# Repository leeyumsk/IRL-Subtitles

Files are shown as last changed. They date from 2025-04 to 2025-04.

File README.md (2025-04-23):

# IRL-Subtitles

Using techniques similar to human perception to localize sounds and speakers.

## Project Details

The final goal of the project is to make AR-Glasses that can display text taken from microphones to be displayed on a heads up display to the user. The system integrates a microphone array, and a camera to localize sound, transcribe speech, and visually present captions on a laptop screen connected to the glasses. This project would ideally be combined with a smart glass display/platform in the future.

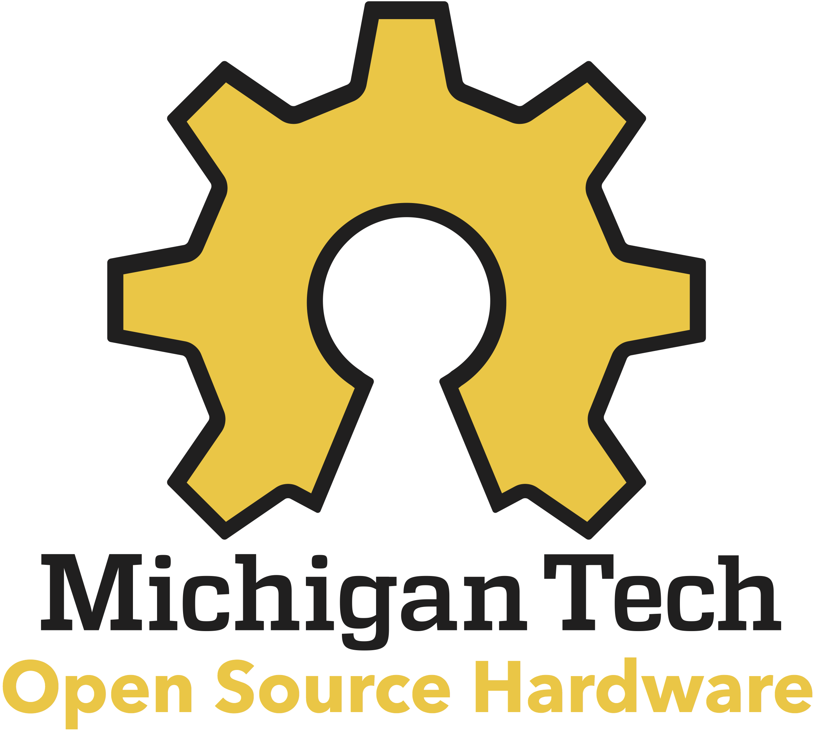
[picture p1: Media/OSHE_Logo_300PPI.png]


## Current State
The current state of the project is that there is no processing that is happening locally on the board, all the data is being streamed over to a computer to be processed and displayed. There are one ESP32-S3 wroom 1U that are being used to get audio and one ESP32-S3 eye that is acting as an AP, camera, and handling the data routing. This is a battery powered data colletion unit.

## Project Structure
The project consists of:
1. [Firmware](#1-firmware)
2. [Software](#2-software)
3. [Hardware](#3-hardware)
4. [Extra Documentation](#4-extra-documentation)

Each is structured into their own folders, and sub groups.

### 1. [Firmware](/Firmware/README.md)
This is the code that is running on the ESP32. Most of the code here is for data collection and transmission. This code has two main parts, one that will go on the arm board and one that goes on the eye. This was made, built, and flashed using vscode. 

#### Requirements
- ESP32 IDF
- Target set to ESP32-S3

### 2. [Software](/Software/README.md)
This is the code that will be run on the computer to process the data that is streamed. Due to time constraints the integration of the audio localization was not included in the OpenCV and speech to text display.

### 3. [Hardware](/Hardware/README.md)
This has both the PBC and KiCad files and the glasses cad models.
The main components are:
1. Arm boards - Holds the power management and mics that collect teh audio data.
2. ESP32S3 eye - Collects the visual data and acts as an access point to route the data.
3. [PowerBoost 1000 Charger](https://www.adafruit.com/product/2465) this handle the battery.
4. Frames - Holds all components in a glasses form to be a wearable design.

#### KiCad
This has the KiCad models that were to produce the boards. That includes the schematics, the PCB files, and gerber files to order the glasses.

#### Onshape
Onshape was used to the frames that the PCBs will fit in on the glasses.

### 4. [Extra Documentation](/Extra%20Documentation/README.md)
This is all the documentation that was created in the testing and researching on creating the glasses. This also has the pin outs that were used on the glasses for reference.

## What the Project could use
1. Faster processing, moving computation on the the board.
2. Better integration between programs, face detect, sound location, and speech to text.
3. Localization of sound implemented. 
4. Battery management within code.
5. Redesign/flip the ports for the eye adapter board be able to connect to eye.

## Helpful Links
https://github.com/espressif/esp-who/tree/master

## References

[ESP-idf examples softAP](https://github.com/espressif/esp-idf/blob/master/examples/wifi/getting_started/softAP/main/softap_example_main.c)

[ESP-idf examples station](https://github.com/espressif/esp-idf/tree/master/examples/wifi/getting_started/station)

[espressif esp-who ESP32-S3-EYE](https://github.com/espressif/esp-who/blob/master/docs/en/get-started/ESP32-S3-EYE_Getting_Started_Guide.md)

[GitHub Doc](https://docs.github.com/en/get-started/writing-on-github/getting-started-with-writing-and-formatting-on-github/basic-writing-and-formatting-syntax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)

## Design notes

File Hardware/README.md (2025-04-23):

# Hardware
All of the hardware for the project.

## PCB

The PCB has gone through many revisions before it was eventually ordered and printed. The older version are in previous versions branch.

### Version 3.2
Version 3.2 is tha iteration that is used for this guide, where there in now only one ESP32-S3 on the sides of the frames. This has two spots to place a battery on where the battery WITH LOW BATTERY SHUTOFF to the board and on to use with a socketed BMS designed like the one from adafuit, [PowerBoost 500 Charger](https://www.adafruit.com/product/1944). The adapter for the eye has also change to pass through the audio data to the other board.

Version 3.2
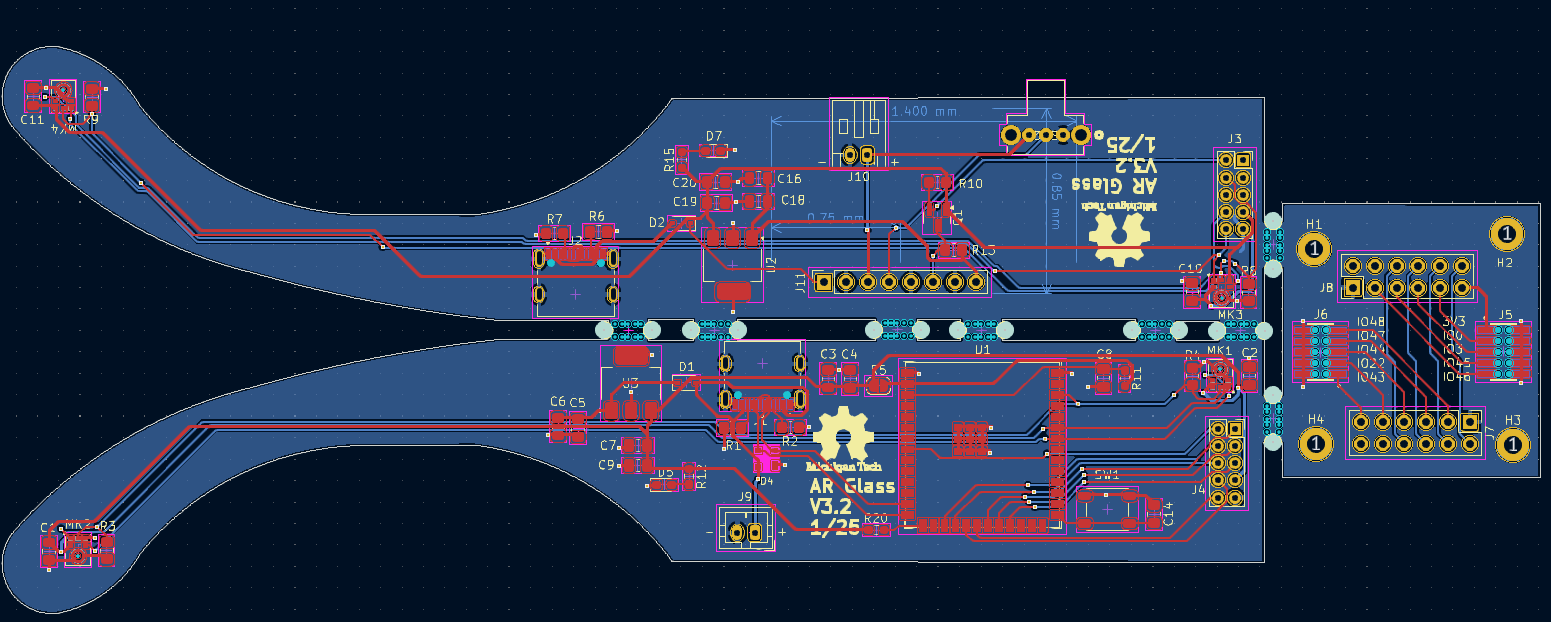
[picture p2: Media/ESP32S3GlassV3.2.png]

These are the pin out for the arm boards.
|Right| | |Left| | 
| --- | --- | - | --- | --- |
| GPIO 15 | GPIO 13 (WS) | | GND | WS | 
| GPIO 9 | GPIO 14 (SCK) | | 3V3 | SCK| 
| GPIO 10 | GPIO 21 (SD) | | x | x | 
| GPIO 11 | 3V3 | | x | SDin | 
| GPIO 12 | GND | | x | LB3v3 |

Eye Adapter Board pins:
| Top | | | | | |
| --- | ----- | ----- | ---- | ---- | ---- |
| x | x | LB3v3 | SD | SCK | WS|
| GND | IO46 | IO45 | IO3 | IO0 | 3V3 | 
| Bottom | | | | | |
| IO43 | IO21 | IO44 | IO47 | IO48 | GND |
| X | LB3v3 | SD | SCK | WS | 3V3 | 

In the hardware folder is all the production files that is needed to order the PCBs.

## Frames
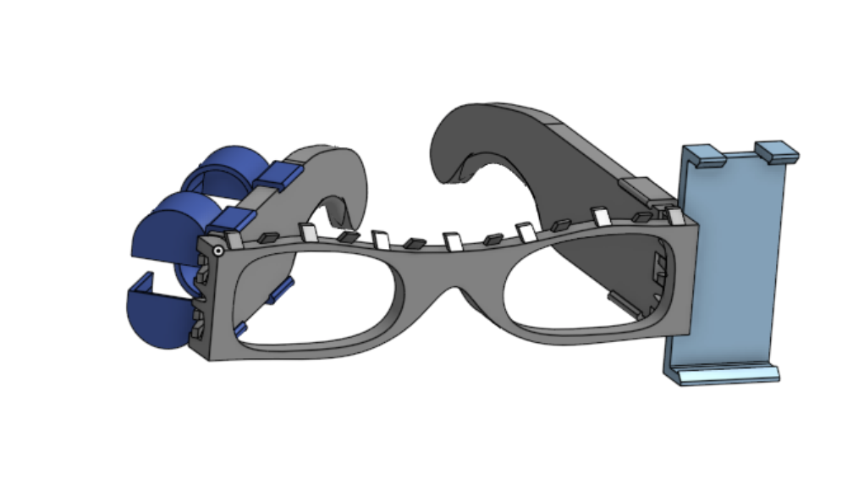
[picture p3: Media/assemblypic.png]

The frames are designed to clip together without requiring a trip to the hardware store.
The CAD model is parametrically modeled to assist with personalization.
The CAD work was done in onshape and is publicly available.
https://cad.onshape.com/documents/a7485a7ae3b222abdb51885d/w/8202e3e3be7d45f8a3fb9981/e/ac120f3095f84bb498783c7c

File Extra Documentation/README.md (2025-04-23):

# Extra Documentation

Here is where all the different files on the components, configurations, testing documents are located.

## Pin outs

(*reference to image in folder img added later once glasses are fully put together*)

Arm boards:
|Right| | |Left| | 
| --- | --- | - | --- | --- |
| GPIO 15 | GPIO 13 (WS) | | GND | WS | 
| GPIO 9 | GPIO 14 (SCK) | | 3V3 | SCK| 
| GPIO 10 | GPIO 21 (SD) | | x | x | 
| GPIO 11 | 3V3 | | x | SDin | 
| GPIO 12 | GND | | x | LB3v3 |

GPIO 41, 42, and 2 are used for the mics

There are more free pin on the ESP32S3 that are currently not being used, refer to the ESP32S3 documentation to see what pins are not tied to other functions. There is no reset button so boards will need to manually unplugged with the button held down for the first time.

Eye Adapter Board pins:
| Top | | | | | |
| --- | ----- | ----- | ---- | ---- | ---- |
| x | x | LB3v3 | SD | SCK | WS|
| GND | IO46 | IO45 | IO3 | IO0 | 3V3 | 
| Bottom | | | | | |
| IO43 | IO21 | IO44 | IO47 | IO48 | GND |
| X | LB3v3 | SD | SCK | WS | 3V3 | 

## Testing
There was a variety of tests done to figure out some of the specifications of the project.

[Audio localization](/Extra%20Documentation/Audio%20localization.md)

[Testing Audio inputs](/Extra%20Documentation/Tesing%20Audio%20inputs.md)

[Face Detection](/Extra%20Documentation/Face%20Detection.md)

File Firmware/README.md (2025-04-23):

# Firmware

Here is the firmware that will do on the boards. 
For both boards ESP-idf will need to be installed to flash both boards and configured in your chosen IDE. To follow along it is recommend to use VScode.
Install ESP-IDF into VScode from the vscode extensions: Marketplace and follow this guild to configure it on your computer [guide](https://docs.espressif.com/projects/vscode-esp-idf-extension/en/latest/installation.html) and install v5.3.2.

## Arm Boards

To flash the board follow the instructions at [VScode ESP-idf configuration](https://docs.espressif.com/projects/vscode-esp-idf-extension/en/latest/startproject.html) in this [folder, Arm boards/ESP_Arm_Boards_Station](/Firmware/Arm%20Board/ESP32_Arm_Boards_Station). This will route the data though the access point created by the ESP32S3-eye. 

Steps:
1. Configure ESP-idf
In Command Pallette / search type >ESP-IDF: Import ESP-IDF Project

2. Select target device and flashing method
Target Device: esp32s3 usb-jtag
Comp Port: com port of esp32s3 ex. com7
Flash Method: DFU

3. Import vscode configuration files
Type ">ESP-IDF: Add VS Code Configuration Folder" into the search bar
This will over write the current folder to point to where esp-idf is .

4. Build the project
Check that the bottom of the window shows the setting in step 2 (start:DFU, plug:com/port of ESP32, Chip: esp32s3 usb-jtag)

5. Flash Board
Double check the settings at the bottom of the window they should match the setting configured in step two.
Then click the lighting bolt at the bottom of the window. 

Steps 4 and 5 can be combined into 1 step by using the fire symbol that will build, flash, and monitor the board.

### Trouble shooting
There is a python script that can be run to check the output is what is expected. [playAudiofromESP32v7.py](/Firmware/Arm%20Board/ESP32_Arm_Boards_Station/playAudioFromESP32v7.py) creates a wav file that can be analysis to check that all four channels are getting audio data. The channels on the main board (right side) are channels 3 (front) and 4 (back) and on the left are channels 1 (back) and 2 (front). Will need numpy, sounddevice, and requests installed in the python environment. 
If problems arise, use the [ESP32_Arm_Board_AP](/Firmware/Arm%20Board/ESP32_Arm_Boards_AP/) to connect to and run the python script in the folder.
If trouble occurs when flashing close all terminal windows, reopen ESP-IDF terminal and flash using the following command idf.py flash

## ESP32S3-eye

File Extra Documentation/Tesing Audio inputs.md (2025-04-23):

# Audio Methods

This was one of the major things to consider this semester was how to collect the audio. There were two main ways that could be used, analog and digital.

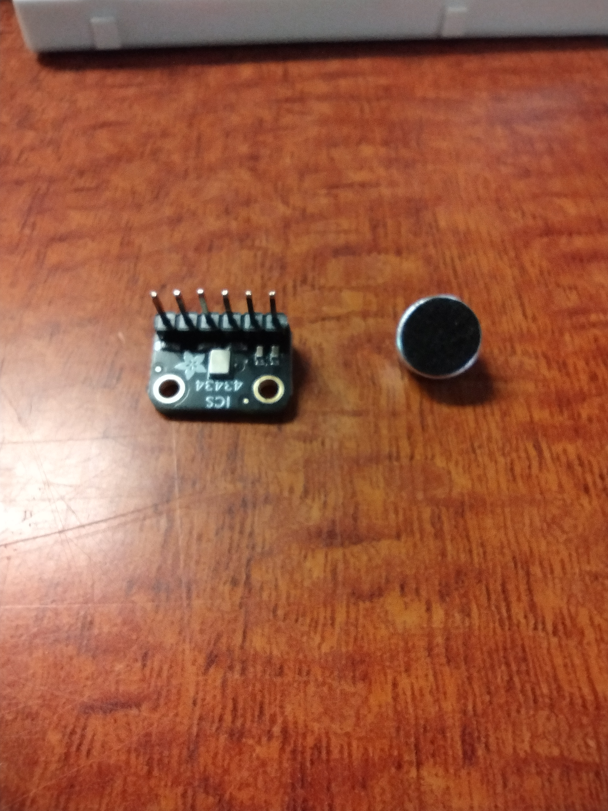
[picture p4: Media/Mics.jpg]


## Analog

To capture analog audio to be sent to the processor, the CMA-4544PF-W electret condenser microphone was used in testing. Analyzing the circuit with the oscilloscope was shown that there was a lot of noise. That there was noise that was getting through the simple filter that was made on the breadboard. This could work but would take up valuable real estate that would be limited on the board. This was coupled with the amount of time that would need to be spent to create a filter to reduce all the noise to manageable levels to process.

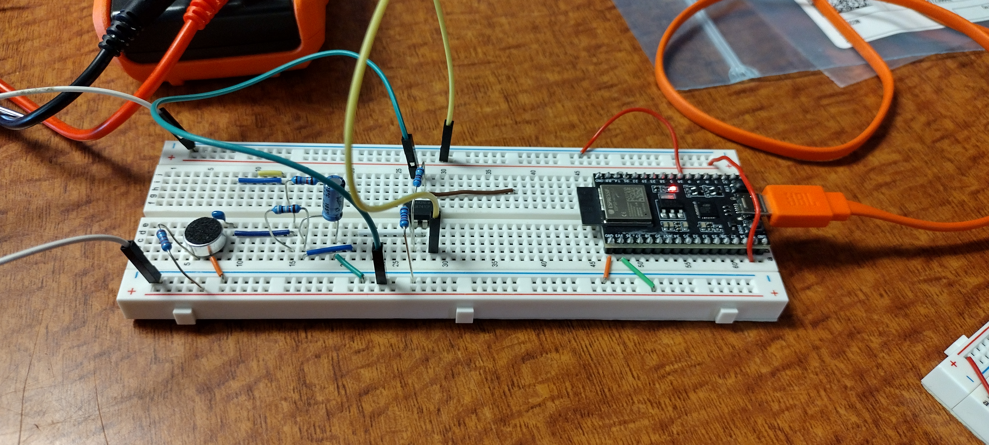
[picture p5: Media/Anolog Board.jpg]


## Digital

To capture digital audio the ICS43434 from adafruit. This works great as it was all compact and easy to breadboard and test. The only problem was to create a test that we could perform without decoding the I2S data stream, a code was needed to capture the audio. This was one of the problems as once audio was able to be captured the processing of the data was not performed correctly, as it was written for the normal esp32 dev kit, not the esp32 s3 devkit.

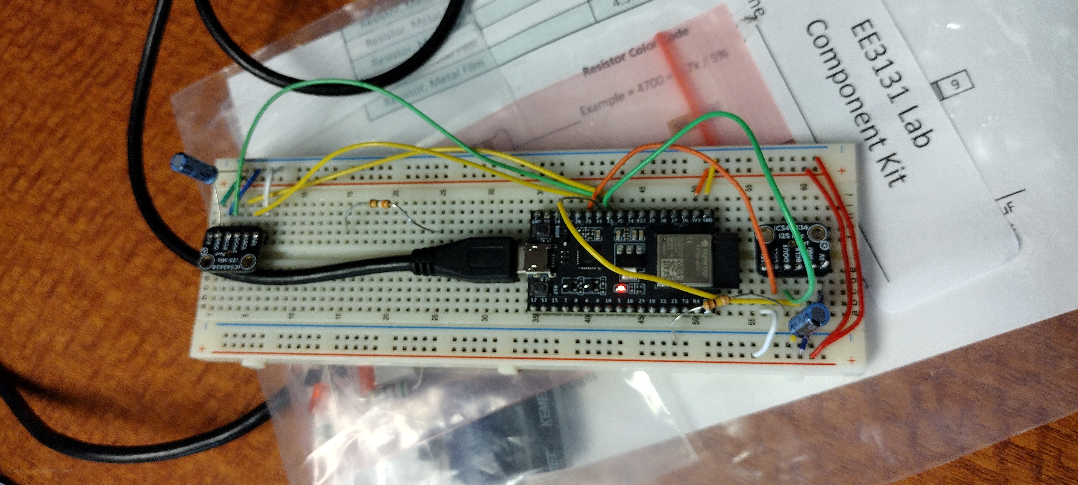
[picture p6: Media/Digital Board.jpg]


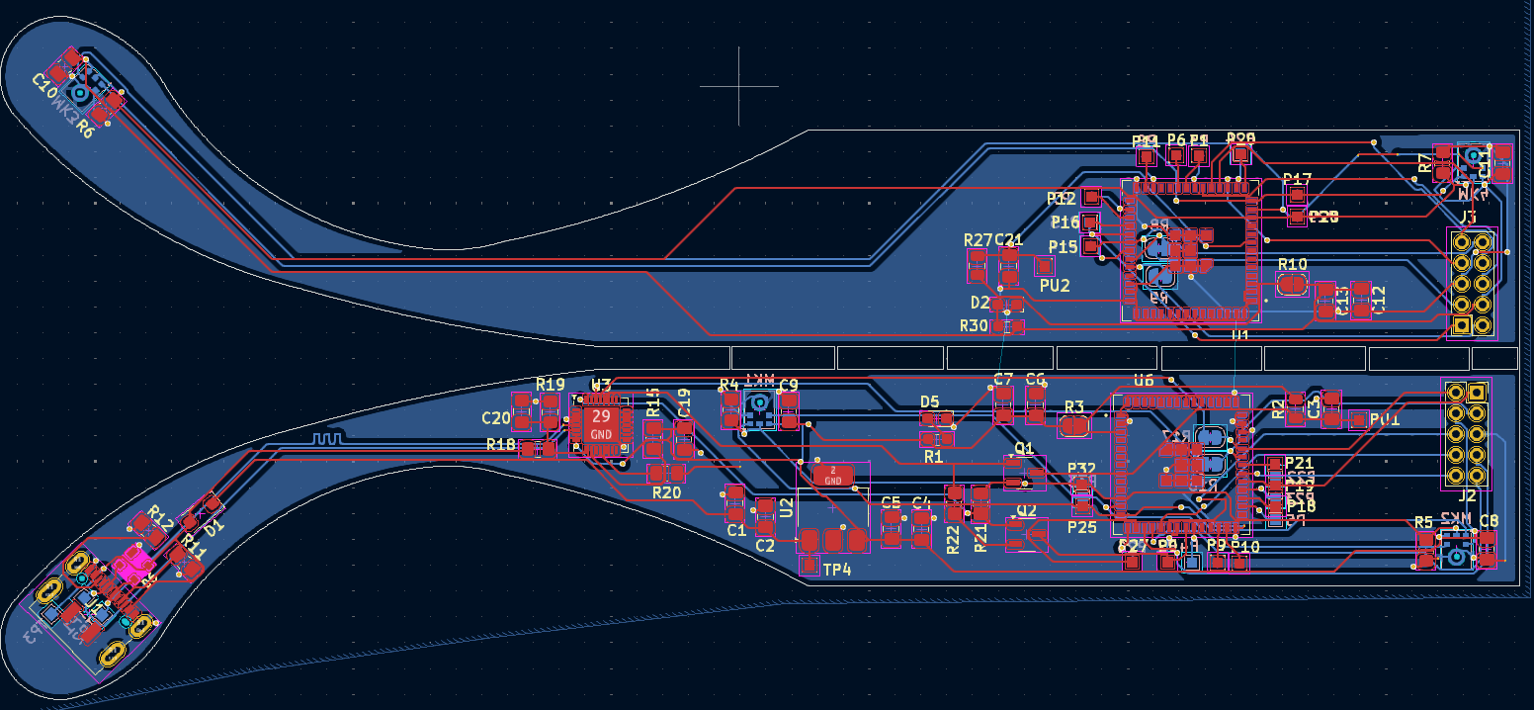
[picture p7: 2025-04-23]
Media/ESP32GlassV1.3.png

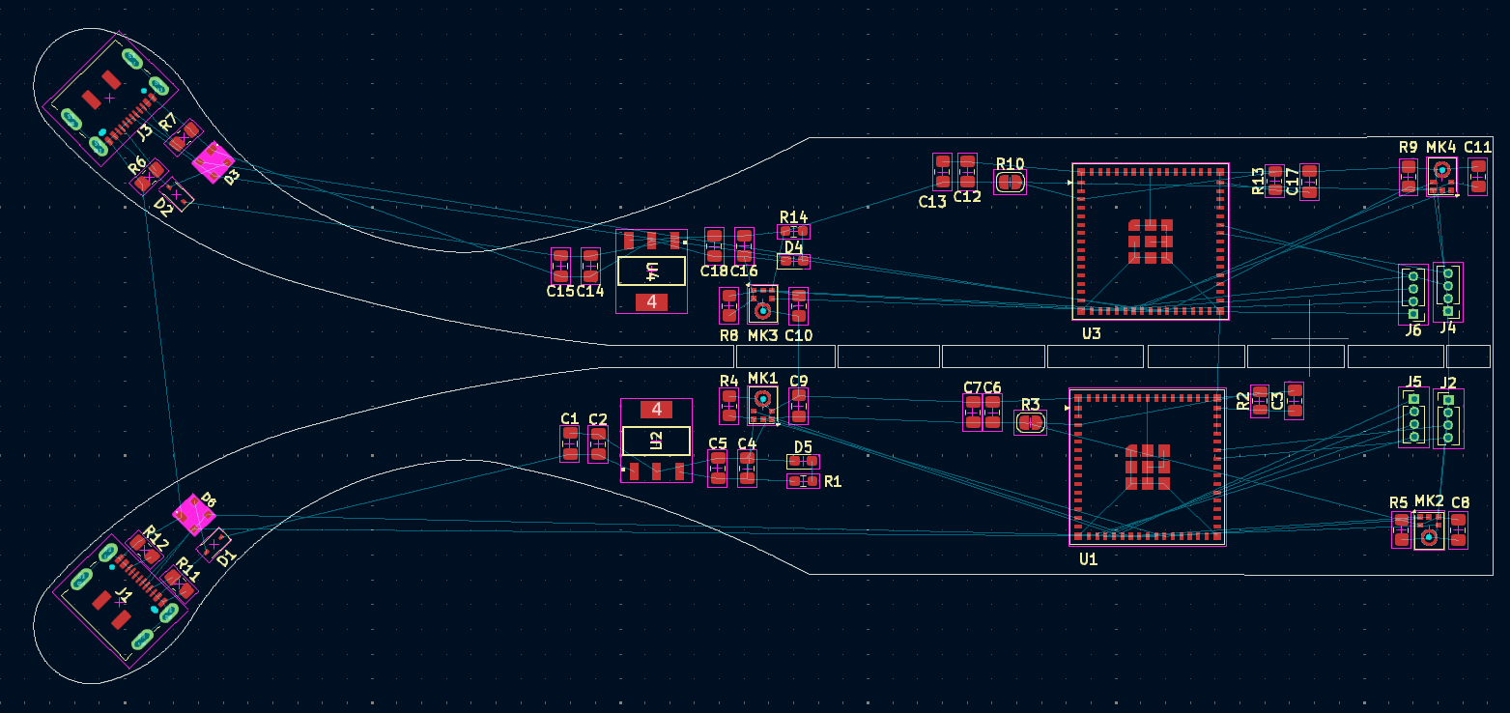
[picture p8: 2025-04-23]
Media/ESP32S3GlassV2.0.png

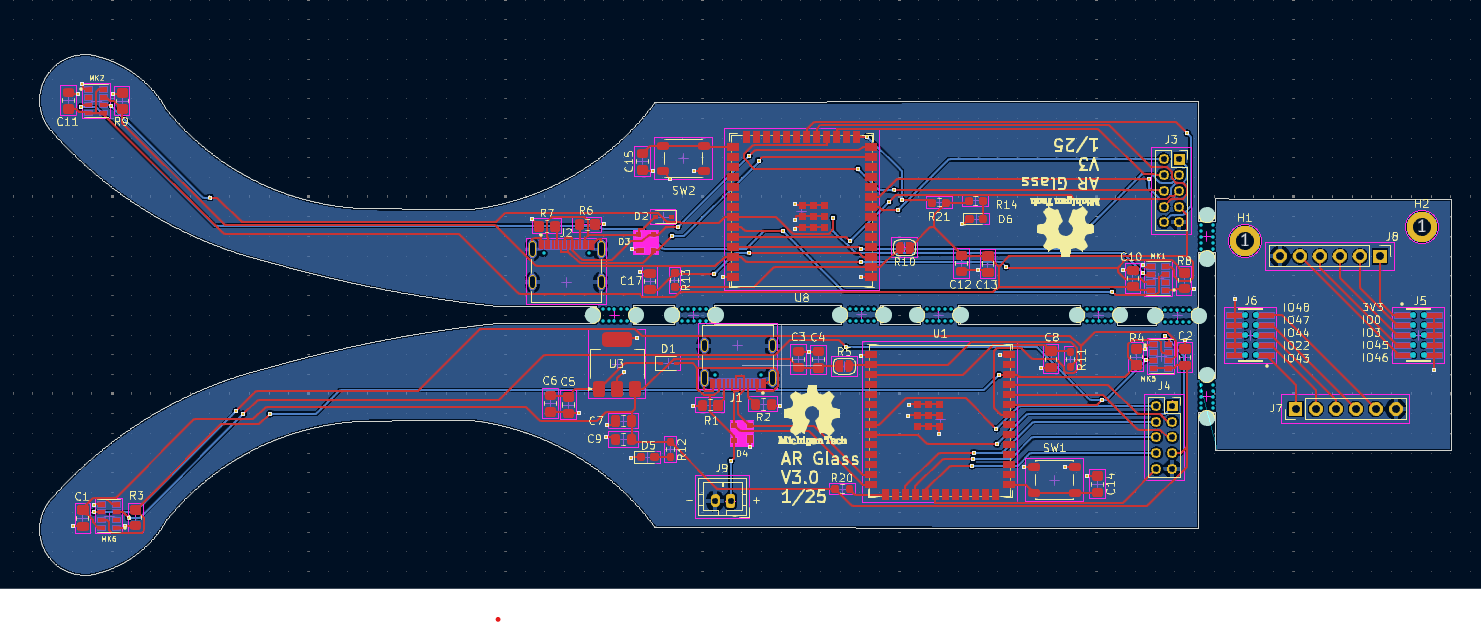
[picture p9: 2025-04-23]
Media/ESP32S3GlassV3.0.png

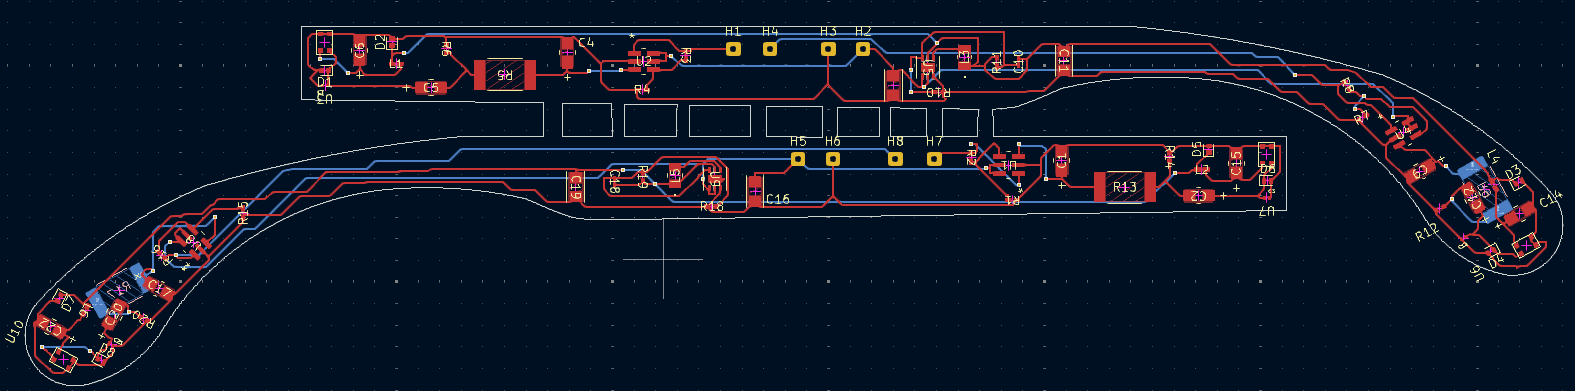
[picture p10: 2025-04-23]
Media/memsBoardV1.png

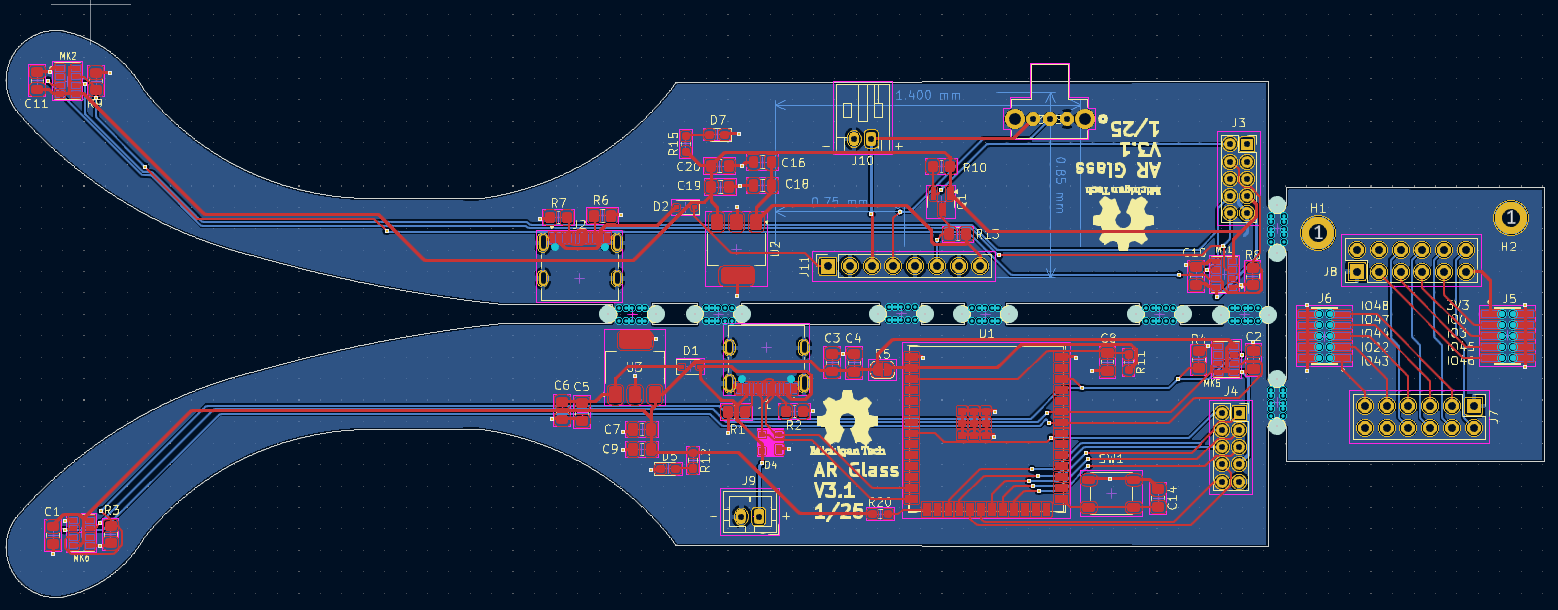
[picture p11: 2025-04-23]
Media/ESP32S3GlassV3.1.png

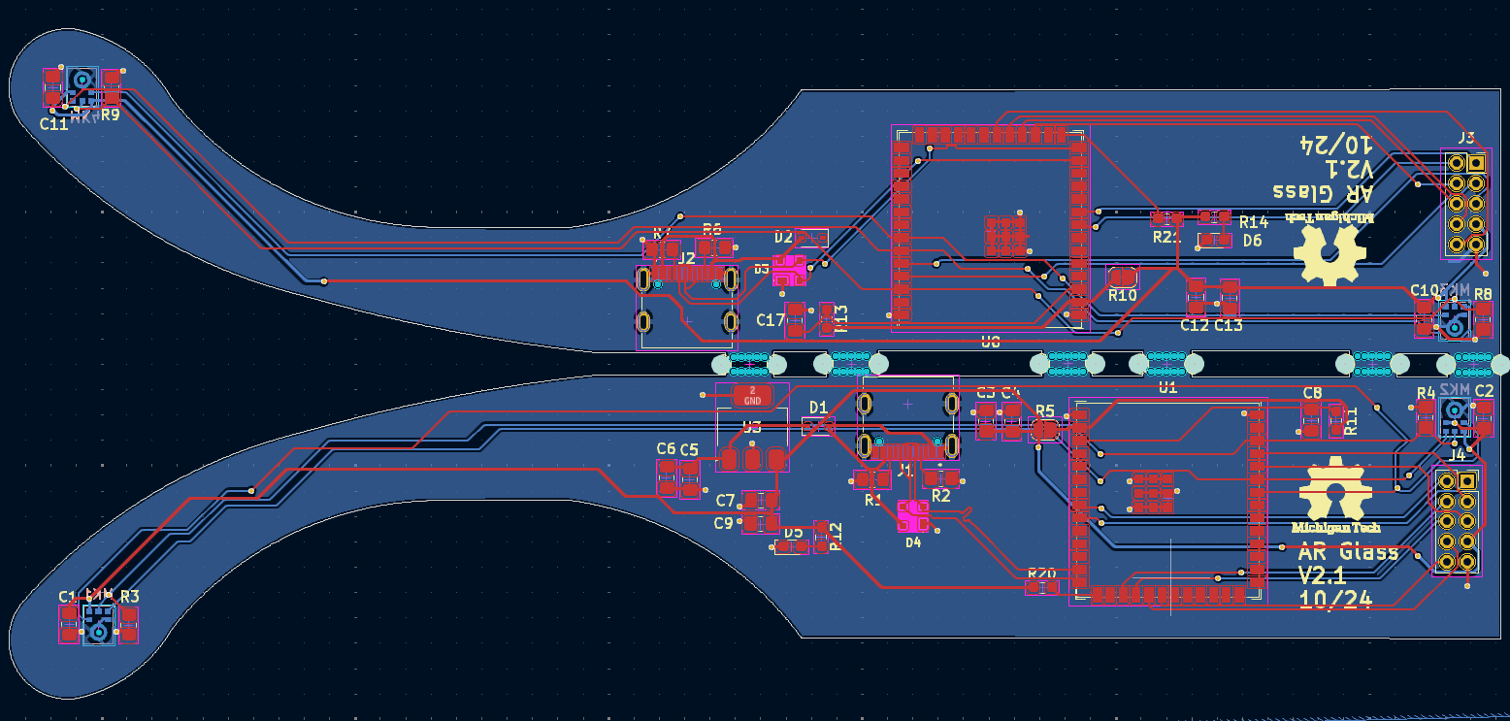
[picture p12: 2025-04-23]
Media/ESP32S3GlassV2.1.png

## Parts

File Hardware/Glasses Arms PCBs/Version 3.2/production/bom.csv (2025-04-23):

Designator | Footprint | Quantity | Value | LCSC Part #
C1, C10, C11, C14, C18, C19, C2, C4, C6, C7 | 0805 | 10 | 0.1uF | C49678
C16, C20, C3, C5, C9 | 0805 | 5 | 10uF | C15850
C8 | 0805 | 1 | 1uF | C89378
D1, D2 | D_SOD-323 | 2 | 1N5819WS | C191023
D4 | SOT143B | 1 | PRTR5V0U2X_215 | C2827688
D5, D7 | 0603 | 2 | LED | C2286
J1, J2 | HRO_TYPE-C-31-M-12 | 2 | USB_C_Receptacle_USB2.0_16P | C165948
J10 | JST_PH_S2B-PH-K_1x02_P2.00mm_Horizontal | 1 | Conn_01x02 | C173752
J11 | PinSocket_1x08_P2.54mm_Vertical | 1 | Conn_01x08_Socket | C27438
J3, J4 | PinSocket_2x05_P2.00mm_Vertical | 2 | PinSocket_2x05_P2.00mm_Vertical | C225304
J5, J6 | GCT_BD050-10-A-1-0500-L-D | 2 | BD050-10-A-0-0500-L-D
J7, J8 | PinHeader_2x06_P2.54mm_Vertical | 2 | PinHeader_2x06_P2.54mm_Vertical
J9 | JST_PH_B2B-PH-K_1x02_P2.00mm_Vertical | 1 | Conn_02x01 | C131337
MK1, MK2, MK3, MK4 | InvenSense_ICS-43434-6_3.5x2.65mm | 4 | ICS-43434 | C5656610
Q1 | SOT-23 | 1 | BSS138 | C78284
R1, R2, R6, R7 | 0805 | 4 | 5.1K | C27834
R10, R13 | 0805 | 2 | 10k | C17414
R11 | 0603 | 1 | 10K | C25804
R12, R15, R20 | 0603 | 3 | 1K | C21190
R3, R4, R8, R9 | 0805 | 4 | 100k | C149504
SW1 | SW_SPST_PTS647_Sx38 | 1 | SW_Push | C92581
SW2 | OS102011MA1QN1_CNK | 1 | OS102011MA1QN1 | C226259
U1 | ESP32-S3-WROOM-1U | 1 | ESP32-S3-WROOM-1U-N8R8 | C2980300
U2 | SOT-223-3_TabPin2 | 1 | LT1963AxST-3.3 | C459918
U3 | SOT-223-3_TabPin2 | 1 | LT1963AEST-3.3 | C459918

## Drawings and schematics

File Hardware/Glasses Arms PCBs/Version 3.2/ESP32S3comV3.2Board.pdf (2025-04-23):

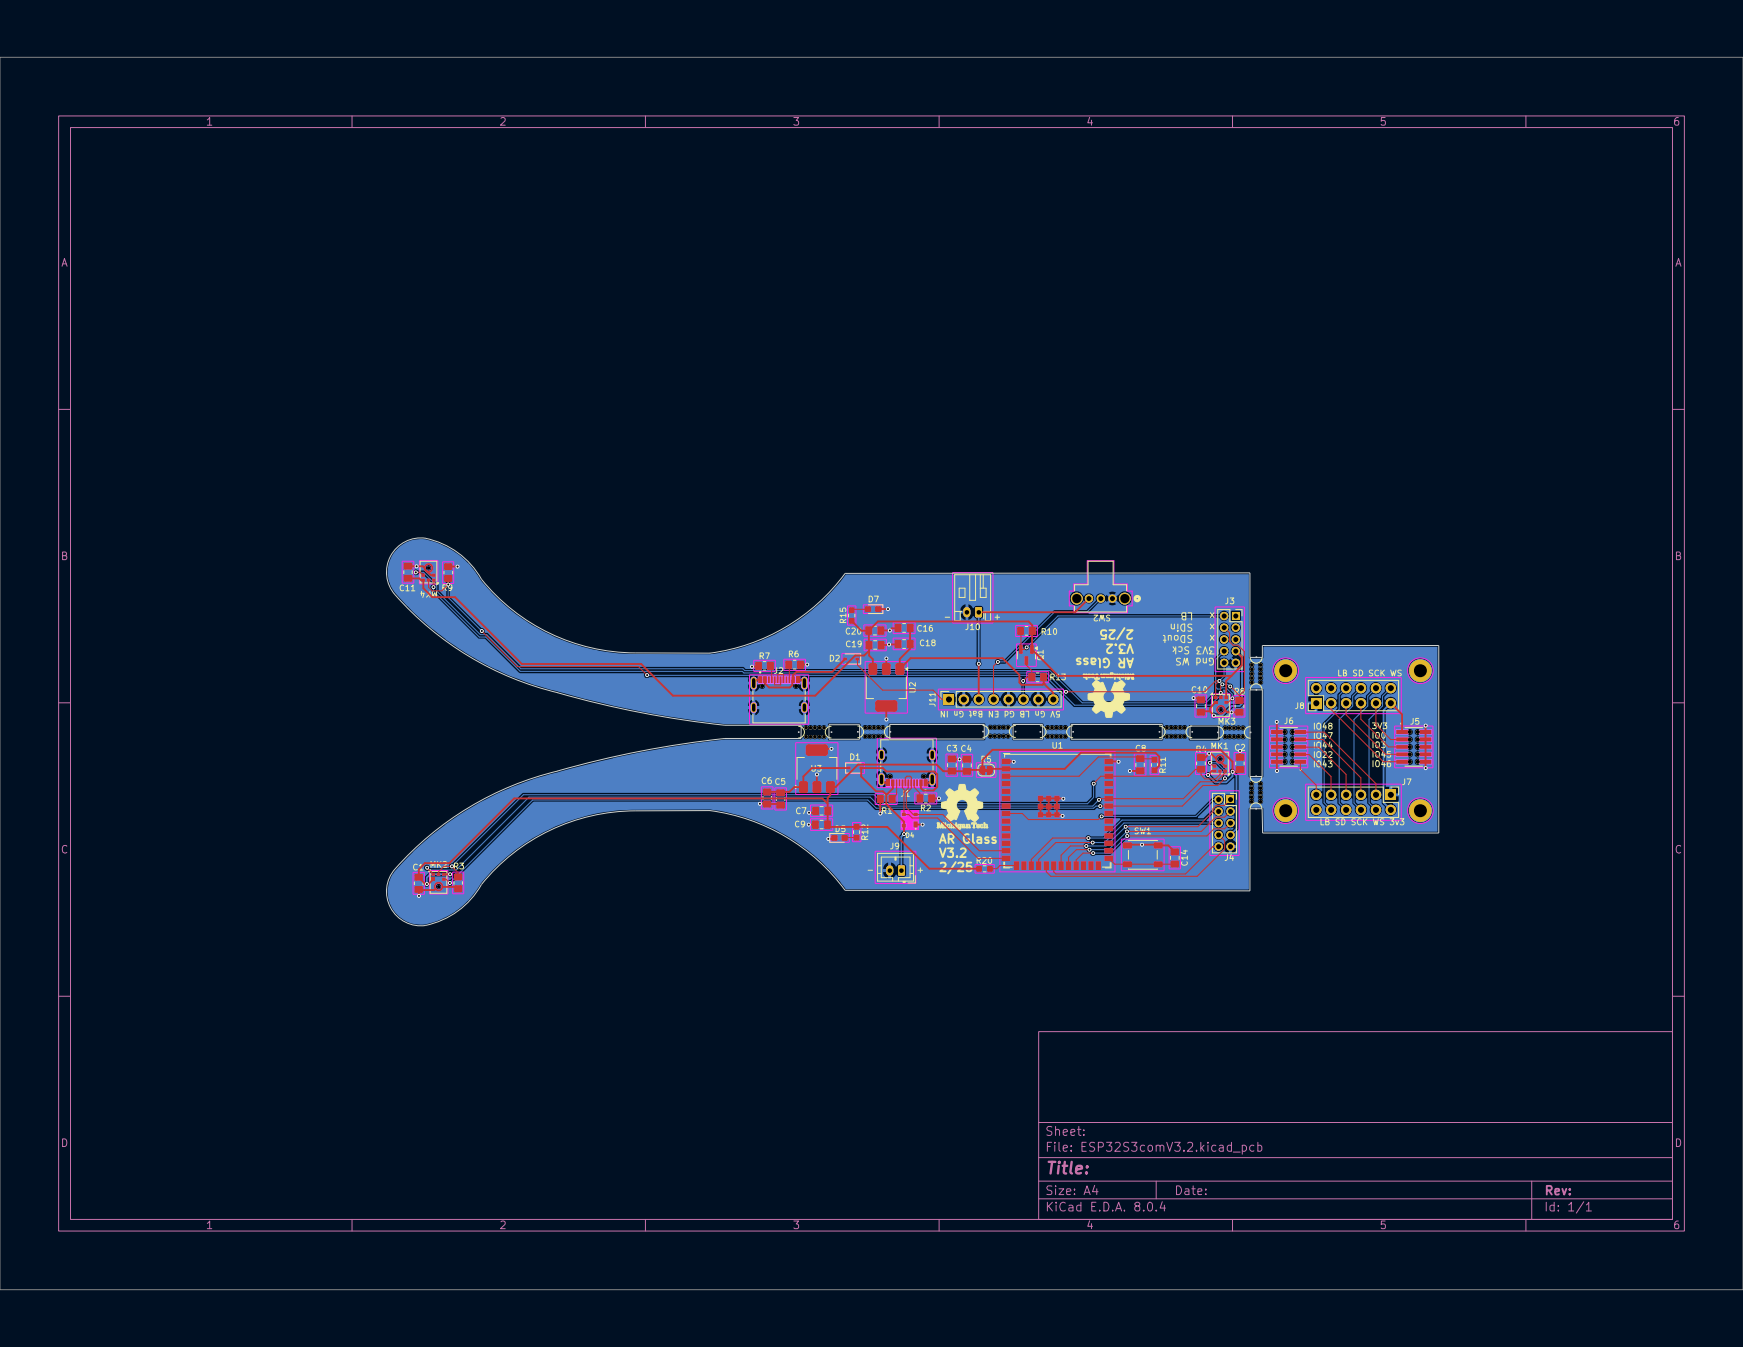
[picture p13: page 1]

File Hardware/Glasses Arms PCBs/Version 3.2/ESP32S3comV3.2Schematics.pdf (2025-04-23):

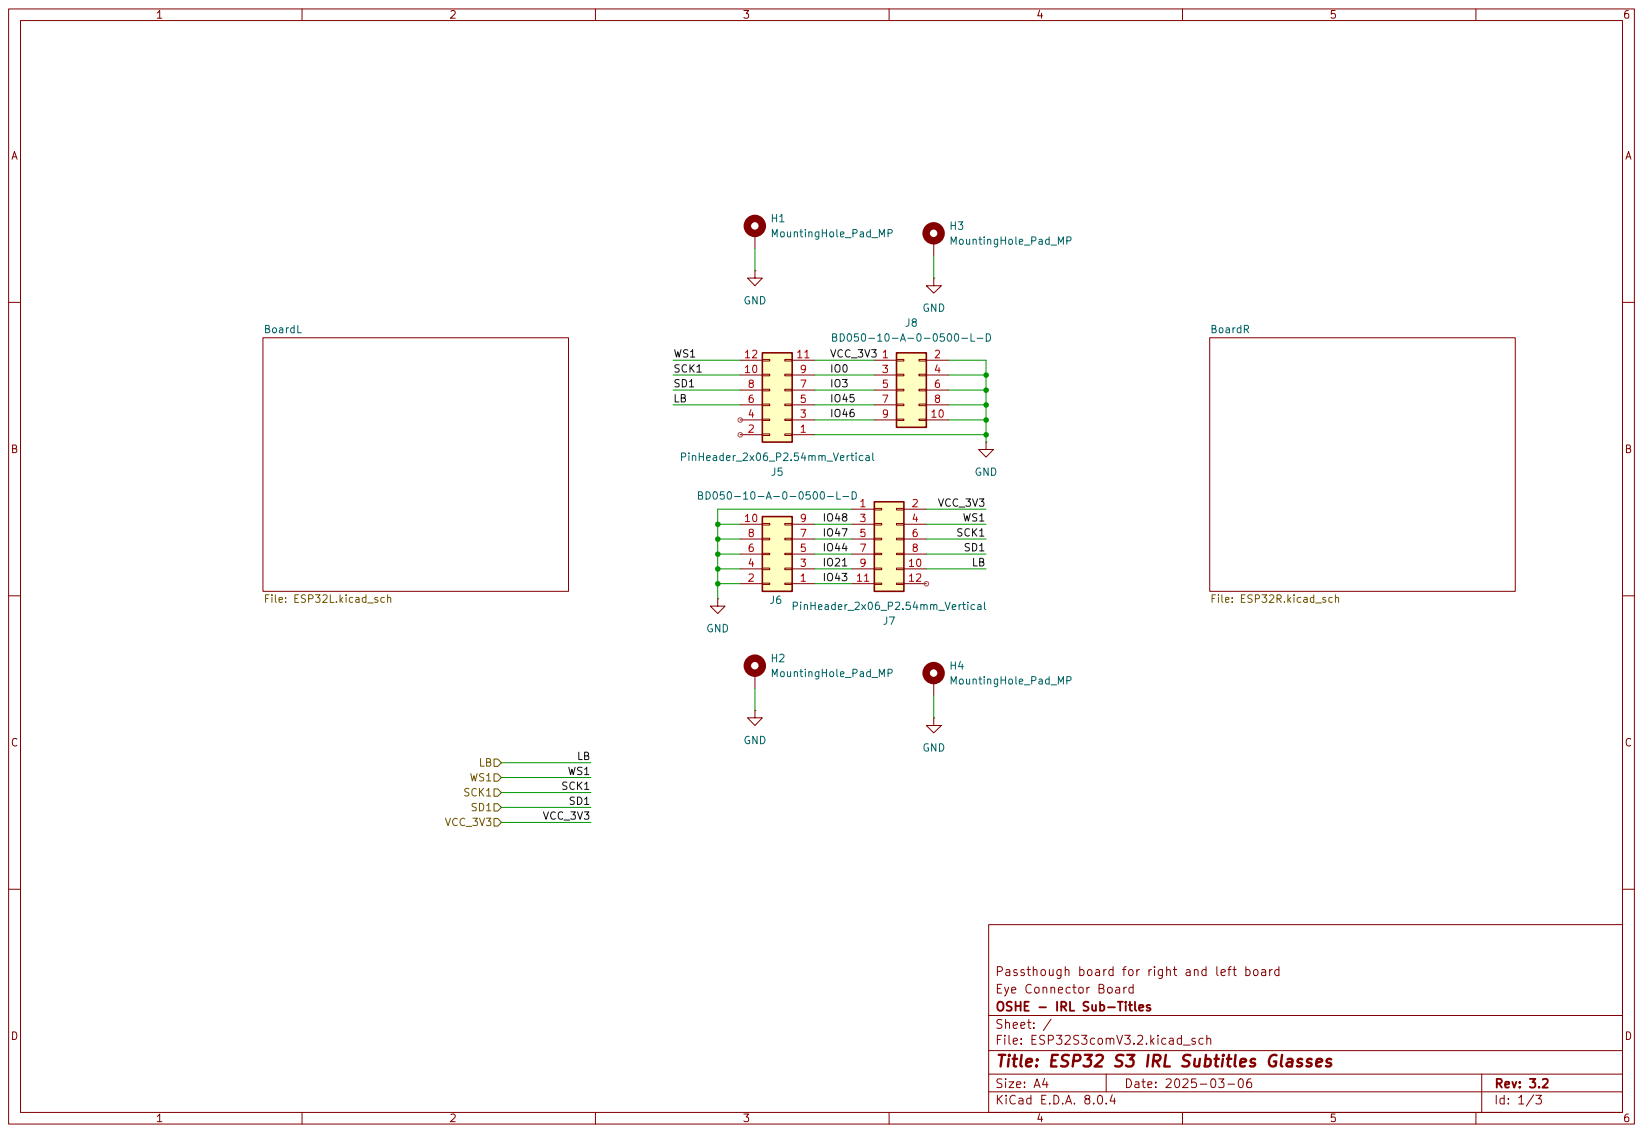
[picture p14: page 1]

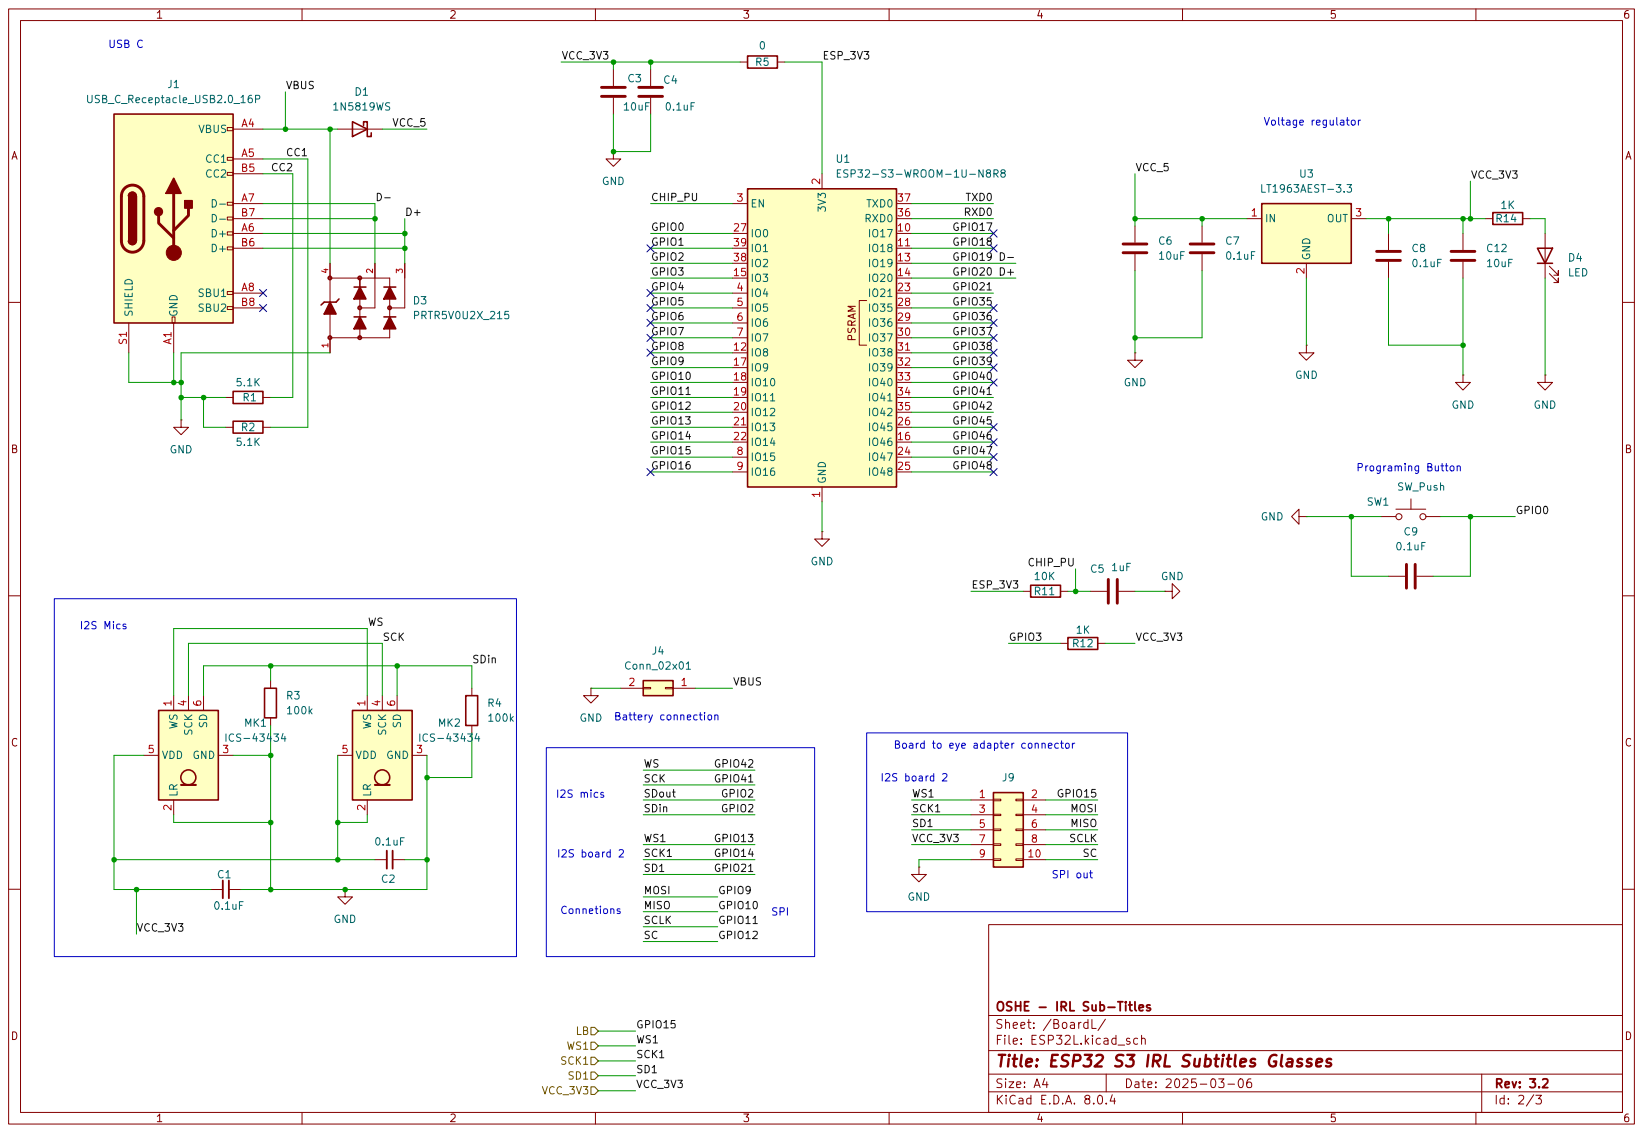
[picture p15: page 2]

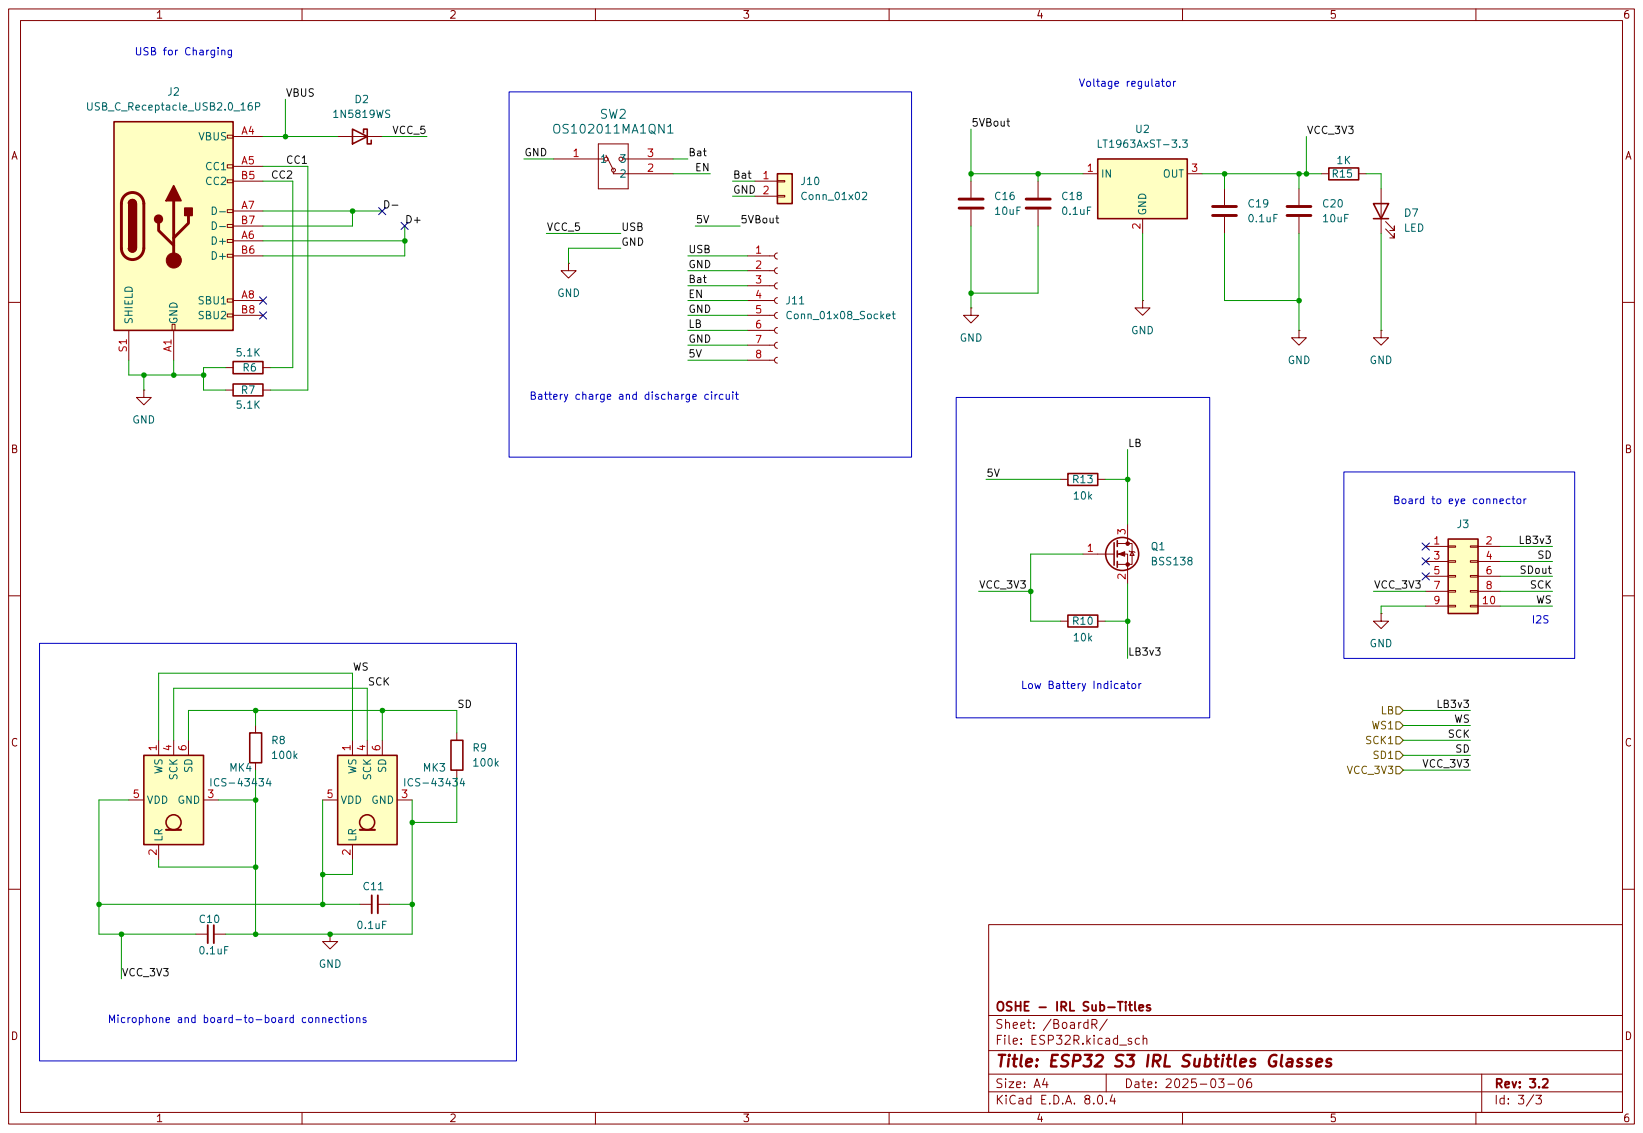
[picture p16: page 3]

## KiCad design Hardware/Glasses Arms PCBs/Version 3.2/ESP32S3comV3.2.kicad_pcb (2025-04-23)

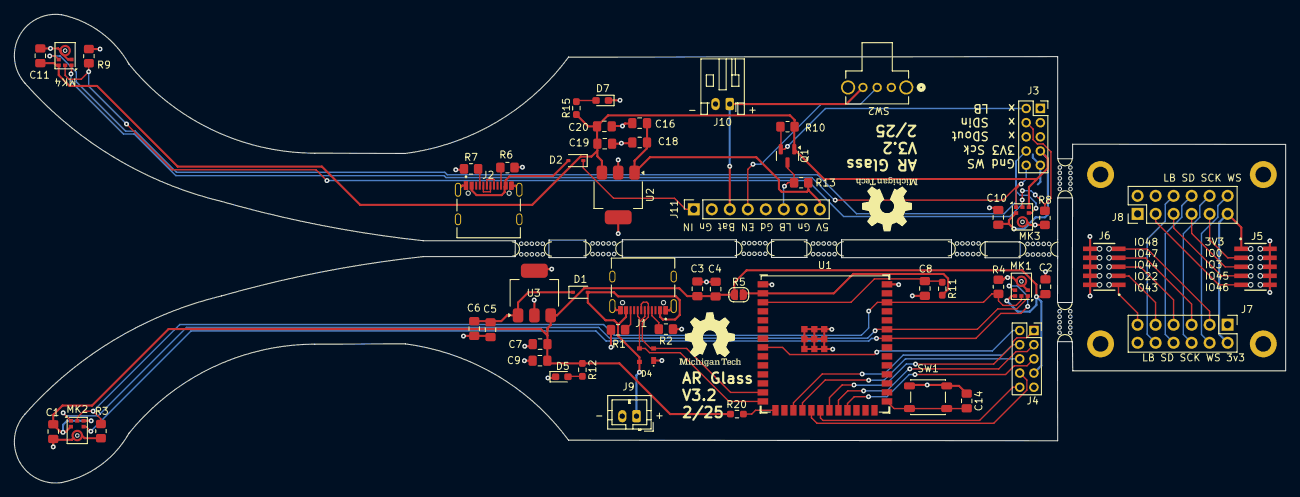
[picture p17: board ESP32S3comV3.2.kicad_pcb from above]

Board: 2 copper layers, 179.3 x 66.1 mm, 69 parts (0 on the bottom side), 54 nets.

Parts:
C1, C2, C4, C6, C7, C10, C11, C14, C18, C19: 0.1uF; C_0805_2012Metric_Pad1.18x1.45mm_HandSolder
C3, C5, C9, C16, C20: 10uF; C_0805_2012Metric_Pad1.18x1.45mm_HandSolder
C8: 1uF; C_0805_2012Metric_Pad1.18x1.45mm_HandSolder
D1, D2: 1N5819WS; D_SOD-323
D4: PRTR5V0U2X_215; SOT143B
D5, D7: LED; LED_0603_1608Metric_Pad1.05x0.95mm_HandSolder
H1, H2, H3, H4: MountingHole_Pad_MP; MountingHole_2.2mm_M2_DIN965_Pad
J1, J2: USB_C_Receptacle_USB2.0_16P; HRO_TYPE-C-31-M-12
J3, J4: PinSocket_2x05_P2.00mm_Vertical
J5, J6: BD050-10-A-0-0500-L-D; GCT_BD050-10-A-1-0500-L-D
J7, J8: PinHeader_2x06_P2.54mm_Vertical
J9: Conn_02x01; JST_PH_B2B-PH-K_1x02_P2.00mm_Vertical
J10: Conn_01x02; JST_PH_S2B-PH-K_1x02_P2.00mm_Horizontal
J11: Conn_01x08_Socket; PinSocket_1x08_P2.54mm_Vertical
MK1, MK2, MK3, MK4: ICS-43434; InvenSense_ICS-43434-6_3.5x2.65mm
Q1: BSS138; SOT-23
R1, R2, R6, R7: 5.1K; R_0805_2012Metric_Pad1.20x1.40mm_HandSolder
R3, R4, R8, R9: 100k; R_0805_2012Metric_Pad1.20x1.40mm_HandSolder
R5: 0; SolderJumper-2_P1.3mm_Open_RoundedPad1.0x1.5mm
R10, R13: 10k; R_0805_2012Metric_Pad1.20x1.40mm_HandSolder
R11: 10K; R_0603_1608Metric_Pad0.98x0.95mm_HandSolder
R12, R15, R20: 1K; R_0603_1608Metric_Pad0.98x0.95mm_HandSolder
SW1: SW_Push; SW_SPST_PTS647_Sx38
SW2: OS102011MA1QN1; OS102011MA1QN1_CNK
U1: ESP32-S3-WROOM-1U-N8R8; ESP32-S3-WROOM-1U
U2: LT1963AxST-3.3; SOT-223-3_TabPin2
U3: LT1963AEST-3.3; SOT-223-3_TabPin2
mouse-bite-3mm-slot, mouse-bite-3mm-slot-2, mouse-bite-3mm-slot-3, mouse-bite-3mm-slot-4, mouse-bite-3mm-slot-5, mouse-bite-3mm-slot-6, mouse-bite-3mm-slot-7, mouse-bite-3mm-slot-8: 0; mouse-bite-3mm-slot

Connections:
/BoardR/5V: C16.1, C18.1, J11.8, R13.1, U2.1 (IN)
/BoardR/Bat: J10.1, J11.3, SW2.3
/BoardR/CC1: J2.A5 (CC1), R7.2
/BoardR/CC2: J2.B5 (CC2), R6.2
/BoardR/D+: J2.A6 (D+), J2.B6 (D+)
/BoardR/D-: J2.A7 (D-), J2.B7 (D-)
/BoardR/EN: J11.4, SW2.2
/BoardR/LB: J11.6, Q1.3 (D), R13.2
/BoardR/LB3v3: J3.2, Q1.2 (S), R10.2
/BoardR/SCK: J3.8, MK3.4 (SCK), MK4.4 (SCK)
/BoardR/SDin: J3.4, MK3.6 (SD), MK4.6 (SD), R8.1, R9.1
/BoardR/USB: D2.1 (K), J11.1
/BoardR/VBUS: D2.2 (A), J2.A4 (VBUS), J2.A9 (VBUS), J2.B4 (VBUS), J2.B9 (VBUS)
/BoardR/VCC_3V3: C10.1, C11.1, C19.1, C20.1, J3.7, MK3.2 (LR), MK3.5 (VDD), MK4.5 (VDD), Q1.1 (G), R10.1, R15.1, U2.3 (OUT)
/BoardR/WS: J3.10, MK3.1 (WS), MK4.1 (WS)
/CC1: J1.A5 (CC1), R2.2
/CC2: J1.B5 (CC2), R1.2
/CHIP_PU: C8.1, R11.1, U1.3 (EN)
/D+: D4.3, J1.A6 (D+), J1.B6 (D+), U1.14 (IO20)
/D-: D4.2, J1.A7 (D-), J1.B7 (D-), U1.13 (IO19)
/ESP_3V3: R5.2, R11.2, U1.2 (3V3)
/Eye connect/IO0: J5.3, J8.9
/Eye connect/IO3: J5.5, J8.7
/Eye connect/IO21: J6.3, J7.9
/Eye connect/IO43: J6.1, J7.11
/Eye connect/IO44: J6.5, J7.7
/Eye connect/IO45: J5.7, J8.5
/Eye connect/IO46: J5.9, J8.3
/Eye connect/IO47: J6.7, J7.5
/Eye connect/IO48: J6.9, J7.3
/Eye connect/LB: J7.10, J8.6
/Eye connect/SCK1: J7.6, J8.10
/Eye connect/SD1: J7.8, J8.8
/Eye connect/VCC_3V3: J5.1, J7.2, J8.11
/Eye connect/WS1: J7.4, J8.12
/GPIO0: C14.2, SW1.2, U1.27 (IO0)
/GPIO2: MK1.6 (SD), MK2.6 (SD), R3.1, R4.1, U1.38 (IO2)
/GPIO3: R20.1, U1.15 (IO3)
/GPIO9: J4.4, U1.17 (IO9)
/GPIO10: J4.6, U1.18 (IO10)
/GPIO11: J4.8, U1.19 (IO11)
/GPIO12: J4.10, U1.20 (IO12)
/GPIO13: J4.1, U1.21 (IO13)
/GPIO14: J4.3, U1.22 (IO14)
/GPIO15: J4.2, U1.8 (IO15)
/GPIO21: J4.5, U1.23 (IO21)
/GPIO41: MK1.4 (SCK), MK2.4 (SCK), U1.34 (IO41)
/GPIO42: MK1.1 (WS), MK2.1 (WS), U1.35 (IO42)
/VBUS: D1.2 (A), D4.4, J1.A4 (VBUS), J1.A9 (VBUS), J1.B4 (VBUS), J1.B9 (VBUS), J9.1
/VCC_3V3: C1.1, C2.1, C3.1, C4.1, C7.1, C9.1, J4.7, MK1.5 (VDD), MK2.2 (LR), MK2.5 (VDD), R5.1, R12.1, R20.2, U3.3 (OUT)
/VCC_5: C5.1, C6.1, D1.1 (K), U3.1 (IN)
GND: C1.2, C2.2, C3.2, C4.2, C5.2, C6.2, C7.2, C8.2, C9.2, C10.2, C11.2, C14.1, C16.2, C18.2, C19.2, C20.2, D4.1, D5.1 (K), D7.1 (K), J1.A1 (GND), J1.A12 (GND), J1.B1 (GND), J1.B12 (GND), J1.S1 (SHIELD), J2.A1 (GND), J2.A12 (GND), J2.B1 (GND), J2.B12 (GND), J2.S1 (SHIELD), J3.9, J4.9, J5.2, J5.4, J5.6, J5.8, J5.10, J6.2, J6.4, J6.6, J6.8, J6.10, J7.1, J8.1, J9.2, J10.2, J11.2, J11.5, J11.7, MK1.2 (LR), MK1.3 (GND), MK2.3 (GND), MK3.3 (GND), MK4.2 (LR), MK4.3 (GND), R1.1, R2.1, R3.2, R4.2, R6.1, R7.1, R8.2, R9.2, SW1.1, SW2.1, U1.1 (GND), U1.40 (GND), U1.41 (GND), U2.2 (GND), U3.2 (GND)
unnamed: D5.2 (A), R12.2
unnamed: D7.2 (A), R15.2

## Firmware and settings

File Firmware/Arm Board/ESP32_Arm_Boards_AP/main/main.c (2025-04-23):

#include "esp_http_server.h"
#include "esp_log.h"
#include "esp_wifi.h"
#include "nvs_flash.h"
#include "esp_event.h"
#include "esp_netif.h"
#include "freertos/FreeRTOS.h"
#include "freertos/task.h"
#include "freertos/semphr.h"
#include "lwip/err.h"
#include "lwip/sys.h"
#include "esp_mac.h"
#include "driver/i2s_std.h"
#include "driver/gpio.h"
#include "esp_task_wdt.h"
#include "esp_timer.h"
#include "soc/i2s_struct.h"
#include "string.h"

// WiFi configuration
// #define EXAMPLE_ESP_WIFI_SSID      "test_ssid"
// #define EXAMPLE_ESP_WIFI_PASS      "test_pass"
#define EXAMPLE_ESP_WIFI_SSID      "myssid"
#define EXAMPLE_ESP_WIFI_PASS      "mypassword"
#define EXAMPLE_MAX_STA_CONN       4

// I2S configuration
#define I2S_SAMPLE_RATE           24000
#define I2S_BITS_PER_SAMPLE       I2S_BITS_PER_SAMPLE_32BIT
#define I2S_DMA_BUF_COUNT         8
#define I2S_DMA_BUF_LEN           128
#define BUFFER_SIZE               8192 * 2

static const char *TAG = "WiFi_AP_Audio_Stream";

// Audio buffers with volatile qualifier
static volatile uint16_t audio_buffer_0a[BUFFER_SIZE];
static volatile uint16_t audio_buffer_0b[BUFFER_SIZE];
size_t bufIndexA = 0;
size_t bufIndexB = 0;
static volatile bool buffer_sel = true;

// Synchronization primitives
//static SemaphoreHandle_t buffer_mutex = NULL;
static volatile bool stream_active = false;

// Forward declarations
static void wifi_event_handler(void *arg, esp_event_base_t event_base, int32_t event_id, void *event_data);
static esp_err_t wifi_init_softap(void);
// static esp_err_t wifi_init_sta(void);
void setup_i2s(void);
static esp_err_t ach1_handler(httpd_req_t *req);
static void start_webserver(void);
//static void i2s_sampling_task(void *arg);
//static void wifi_task(void *arg);

i2s_chan_handle_t rx_handle_0;
i2s_chan_handle_t rx_handle_1;

// WiFi event handler function for an access point
static void wifi_event_handler(void *arg, esp_event_base_t event_base, int32_t event_id, void *event_data) {
    if (event_id == WIFI_EVENT_AP_STACONNECTED) {
        wifi_event_ap_staconnected_t *event = (wifi_event_ap_staconnected_t *)event_data;
        ESP_LOGI(TAG, "Station "MACSTR" joined, AID=%d", MAC2STR(event->mac), event->aid);
    } else if (event_id == WIFI_EVENT_AP_STADISCONNECTED) {
        wifi_event_ap_stadisconnected_t *event = (wifi_event_ap_stadisconnected_t *)event_data;
        ESP_LOGI(TAG, "Station "MACSTR" left, AID=%d", MAC2STR(event->mac), event->aid);
    }
}

// WiFi initialization function (for AP)
static esp_err_t wifi_init_softap(void) {
    esp_err_t ret;
    
    ESP_LOGI(TAG, "Starting WiFi initialization...");
    
    ret = esp_netif_init();
    if (ret != ESP_OK) {
        ESP_LOGE(TAG, "TCP/IP adapter initialization failed");
        return ret;
    }
    ESP_LOGI(TAG, "TCP/IP adapter initialized");
    
    ret = esp_event_loop_create_default();
    if (ret != ESP_OK) {
        ESP_LOGE(TAG, "Event loop creation failed");
        return ret;
    }
    ESP_LOGI(TAG, "Event loop created");
    
    esp_netif_t *ap_netif = esp_netif_create_default_wifi_ap();
    if (ap_netif == NULL) {
        ESP_LOGE(TAG, "Failed to create WiFi AP netif");
        return ESP_FAIL;
    }
    ESP_LOGI(TAG, "WiFi AP netif created");
    
    wifi_init_config_t cfg = WIFI_INIT_CONFIG_DEFAULT();
    ret = esp_wifi_init(&cfg);
    if (ret != ESP_OK) {
        ESP_LOGE(TAG, "WiFi initialization failed");
        return ret;
    }
    ESP_LOGI(TAG, "WiFi initialized");
    
    ret = esp_event_handler_instance_register(WIFI_EVENT, 
                                            ESP_EVENT_ANY_ID, 
                                            &wifi_event_handler, 
                                            NULL, 
                                            NULL);
    if (ret != ESP_OK) {
        ESP_LOGE(TAG, "Event handler registration failed");
        return ret;
    }
    ESP_LOGI(TAG, "Event handler registered");
    
    wifi_config_t wifi_config = {
        .ap = {
            .ssid = EXAMPLE_ESP_WIFI_SSID,
            .ssid_len = strlen(EXAMPLE_ESP_WIFI_SSID),
            .password = EXAMPLE_ESP_WIFI_PASS,
            .max_connection = EXAMPLE_MAX_STA_CONN,
            .authmode = strlen(EXAMPLE_ESP_WIFI_PASS) ? WIFI_AUTH_WPA_WPA2_PSK : WIFI_AUTH_OPEN
        },
    };
    
    ret = esp_wifi_set_mode(WIFI_MODE_AP);
    if (ret != ESP_OK) {
        ESP_LOGE(TAG, "Failed to set WiFi mode");
        return ret;
    }
    ESP_LOGI(TAG, "WiFi mode set to AP");
    
    ret = esp_wifi_set_config(WIFI_IF_AP, &wifi_config);
    if (ret != ESP_OK) {
        ESP_LOGE(TAG, "Failed to set WiFi config");
        return ret;
    }
    ESP_LOGI(TAG, "WiFi config set");
    
    ret = esp_wifi_start();
    if (ret != ESP_OK) {
        ESP_LOGE(TAG, "Failed to start WiFi");
        return ret;
    }
    ESP_LOGI(TAG, "WiFi started successfully");
    
    return ESP_OK;
}

// I2S setup function
#include "driver/i2s_std.h"
#include "driver/gpio.h"

void setup_i2s(void) {
    ESP_LOGI("I2S", "Initializing I2S peripherals...");
    // === Configure First I2S Peripheral (I2S_NUM_0) ===
    // Define the I2S channel configuration for RX
    i2s_chan_config_t chan_cfg0 = I2S_CHANNEL_DEFAULT_CONFIG(I2S_NUM_0, I2S_ROLE_MASTER);

    // Allocate the RX channel
    if (i2s_new_channel(&chan_cfg0, NULL, &rx_handle_0) != ESP_OK) {
        ESP_LOGE("I2S", "Failed to create I2S_0 RX channel");
        return;
    }

    // Configure the standard I2S settings
    i2s_std_config_t std_cfg0 = {
        .clk_cfg = I2S_STD_CLK_DEFAULT_CONFIG(I2S_SAMPLE_RATE),
        .slot_cfg = I2S_STD_MSB_SLOT_DEFAULT_CONFIG(I2S_DATA_BIT_WIDTH_32BIT, I2S_SLOT_MODE_STEREO),
        .gpio_cfg = {
            .mclk = I2S_GPIO_UNUSED,
            .bclk = GPIO_NUM_14,
            .ws = GPIO_NUM_13,
            .dout = I2S_GPIO_UNUSED,
            .din = GPIO_NUM_21,
            .invert_flags = {
                .mclk_inv = false,
                .bclk_inv = false,
                .ws_inv = false,
            },
        },
    };

    // Initialize the RX channel in standard mode
    if (i2s_channel_init_std_mode(rx_handle_0, &std_cfg0) != ESP_OK) {
        ESP_LOGE("I2S", "Failed to initialize I2S_0 RX channel in standard mode");
        return;
    }

    // Enable the RX channel to start receiving data
    if (i2s_channel_enable(rx_handle_0) != ESP_OK) {
        ESP_LOGE("I2S", "Failed to enable I2S_0 RX channel");
    }

        // === Configure First I2S Peripheral (I2S_NUM_1) ===
    // Define the I2S channel configuration for RX
    i2s_chan_config_t chan_cfg1 = I2S_CHANNEL_DEFAULT_CONFIG(I2S_NUM_1, I2S_ROLE_MASTER);

    // Allocate the RX channel
    if (i2s_new_channel(&chan_cfg1, NULL, &rx_handle_1) != ESP_OK) {
        ESP_LOGE("I2S", "Failed to create I2S_1 RX channel");
        return;
    }

    // Configure the standard I2S settings
    i2s_std_config_t std_cfg1 = {
        .clk_cfg = I2S_STD_CLK_DEFAULT_CONFIG(I2S_SAMPLE_RATE),
        .slot_cfg = I2S_STD_MSB_SLOT_DEFAULT_CONFIG(I2S_DATA_BIT_WIDTH_32BIT, I2S_SLOT_MODE_STEREO),
        .gpio_cfg = {
            .mclk = I2S_GPIO_UNUSED,
            .bclk = GPIO_NUM_41,
            .ws = GPIO_NUM_42,
            .dout = I2S_GPIO_UNUSED,
            .din = GPIO_NUM_2,
            .invert_flags = {
                .mclk_inv = false,
                .bclk_inv = false,
                .ws_inv = false,
            },
        },
    };

    // Initialize the RX channel in standard mode
    if (i2s_channel_init_std_mode(rx_handle_1, &std_cfg1) != ESP_OK) {
        ESP_LOGE("I2S", "Failed to initialize I2S_1 RX channel in standard mode");
        return;
    }

    // Enable the RX channel to start receiving data
    if (i2s_channel_enable(rx_handle_1) != ESP_OK) {
        ESP_LOGE("I2S", "Failed to enable I2S_1 RX channel");
    }
    ESP_LOGI("I2S", "I2S peripherals initialized!");
}


// Start webserver function
static void start_webserver(void) {
    ESP_LOGI(TAG, "Starting webserver initialization...");
    
    httpd_config_t config = HTTPD_DEFAULT_CONFIG();
    config.stack_size = 8192 * 2;
    config.task_priority = tskIDLE_PRIORITY + 5;
    
    httpd_handle_t server = NULL;
    
    ESP_LOGI(TAG, "Starting HTTP server on port: %d", config.server_port);
    
    esp_err_t ret = httpd_start(&server, &config);
    if (ret == ESP_OK) {
        // URI handler structure for GET /audio_stream
        httpd_uri_t audio_stream = {
            .uri       = "/ach1",
            .method    = HTTP_GET,
            .handler   = ach1_handler,
            .user_ctx  = NULL
        };
        
        // Register URI handlers
        ret = httpd_register_uri_handler(server, &audio_stream);
        if (ret == ESP_OK) {
            ESP_LOGI(TAG, "URI handler registered successfully");
        } else {
            ESP_LOGE(TAG, "Failed to register URI handler: %s", esp_err_to_name(ret));
        }
    } else {
        ESP_LOGE(TAG, "Failed to start server: %s", esp_err_to_name(ret));
    }
}

void app_main(void) {
    ESP_LOGI(TAG, "Starting application...");
    
    // Initialize NVS
    esp_err_t ret = nvs_flash_init();
    if (ret == ESP_ERR_NVS_NO_FREE_PAGES || ret == ESP_ERR_NVS_NEW_VERSION_FOUND) {
        ESP_ERROR_CHECK(nvs_flash_erase());
        ret = nvs_flash_init();
    }
    ESP_ERROR_CHECK(ret);
    ESP_LOGI(TAG, "NVS initialized");
        
    ESP_LOGI(TAG, "Initializing WiFi in SoftAP Mode");
    
        // Initialize WiFi
        ret = wifi_init_softap();
        if (ret != ESP_OK) {
            ESP_LOGE(TAG, "WiFi initialization failed");
            vTaskDelete(NULL);
            return;
        }
        ESP_LOGI(TAG, "WiFi Initilization Successful");
    
    ESP_LOGI(TAG, "Starting webserver");
    // Start webserver
    start_webserver();
    ESP_LOGI(TAG, "Webserver initialization Successfully");
    
    ESP_LOGI(TAG, "WiFi task completed initialization");

    // Initialize I2S
    setup_i2s();
    
    ESP_LOGI(TAG, "Application initialization completed");
}

//Update the two lines below after 2 channels work
//Current code right now should work but is only using 1 microphone, need to add the second one and the buffer handling
//Maybe add a mutex or semaphore before buffer switching? But last time that caused issues with the I2S reading (cause of delays)

//for multiple channels and "audio/raw", the data is expected to be interleaved
// ex: [sample0, sample1] for two channels or [sample0, sample1, sample2, sample3] for four channels
// audio is packed the same way in .wav format, so it should be easy to take this and make a .wav file with two or four channels 
static esp_err_t ach1_handler(httpd_req_t *req) {
    ESP_LOGI(TAG, "Audio handler started");
    esp_err_t res = ESP_OK;
    
        // Set response type and headers
    if ((res = httpd_resp_set_type(req, "audio/raw")) != ESP_OK) {
        ESP_LOGE(TAG, "Failed to set response type: %s", esp_err_to_name(res));
        goto cleanup;
    }
    
    if ((res = httpd_resp_set_hdr(req, "X-Audio-Sample-Rate", "24000")) != ESP_OK ||
        (res = httpd_resp_set_hdr(req, "X-Audio-Bits-Per-Sample", "16")) != ESP_OK ||
        (res = httpd_resp_set_hdr(req, "X-Audio-Channels", "4")) != ESP_OK) {
        ESP_LOGE(TAG, "Failed to set audio headers: %s", esp_err_to_name(res));
        goto cleanup;
    }

    size_t bytes_read = 0;
    uint32_t raw_sample[4];  // Buffer to hold raw left0, right0, left1, and right1 samples
    
    while (true) {
        if (httpd_req_to_sockfd(req) < 0) {
            ESP_LOGI(TAG, "Client disconnected");
            goto cleanup;
        }
        // Read from I2S
        if (buffer_sel) {
            //ESP_LOGI(TAG, "Filling buffer A");
            for (bufIndexA = 0; bufIndexA < BUFFER_SIZE; bufIndexA += 4) {
                if ((i2s_channel_read(rx_handle_0, raw_sample, sizeof(uint32_t) * 2, &bytes_read, portMAX_DELAY)) == ESP_OK &&\
                    (i2s_channel_read(rx_handle_1, &raw_sample[2], sizeof(uint32_t) * 2, &bytes_read, portMAX_DELAY)) == ESP_OK) {
                    audio_buffer_0a[bufIndexA] = (uint16_t)((raw_sample[0] & 0xFFFF000) >> 12);
                    audio_buffer_0a[bufIndexA+1] = (uint16_t)((raw_sample[1] & 0xFFFF000) >> 12);
                    audio_buffer_0a[bufIndexA+2] = (uint16_t)((raw_sample[2] & 0xFFFF000) >> 12);
                    audio_buffer_0a[bufIndexA+3] = (uint16_t)((raw_sample[3] & 0xFFFF000) >> 12);
                }
            }
            //Transmitting buffer A
            res = httpd_resp_send_chunk(req, (const char *)audio_buffer_0a, BUFFER_SIZE * sizeof(uint16_t));
            bufIndexA = 0;

            buffer_sel = false;

        }else{
            ESP_LOGI(TAG, "Filling buffer B");
            for (bufIndexB = 0; bufIndexB < BUFFER_SIZE; bufIndexB += 4) {
                if ((i2s_channel_read(rx_handle_0, raw_sample, sizeof(uint32_t) * 2, &bytes_read, portMAX_DELAY)) == ESP_OK &&\
                (i2s_channel_read(rx_handle_1, &raw_sample[2], sizeof(uint32_t) * 2, &bytes_read, portMAX_DELAY)) == ESP_OK) {
                    audio_buffer_0b[bufIndexB] = (uint16_t)((raw_sample[0] & 0xFFFF000) >> 12);
                    audio_buffer_0b[bufIndexB+1] = (uint16_t)((raw_sample[1] & 0xFFFF000) >> 12);
                    audio_buffer_0b[bufIndexB+2] = (uint16_t)((raw_sample[2] & 0xFFFF000) >> 12);
                    audio_buffer_0b[bufIndexB+3] = (uint16_t)((raw_sample[3] & 0xFFFF000) >> 12);
                }
            }
            //Transmitting buffer B
            res = httpd_resp_send_chunk(req, (const char *)audio_buffer_0b, BUFFER_SIZE * sizeof(uint16_t));
            bufIndexB = 0;

            buffer_sel = true;
        }
        
        if (res != ESP_OK) {
            ESP_LOGE(TAG, "Failed to send chunk: %s", esp_err_to_name(res));
            goto cleanup;
        }

        // Small delay to prevent watchdog issues
        //vTaskDelay(1);
    }

cleanup:
    return res;
}

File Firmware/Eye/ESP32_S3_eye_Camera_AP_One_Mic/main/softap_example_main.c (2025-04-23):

#include <string.h>
#include "freertos/FreeRTOS.h"
#include "freertos/task.h"
#include "esp_mac.h"
#include "esp_wifi.h"
#include "esp_event.h"
#include "esp_log.h"
#include "nvs_flash.h"
#include "esp_camera.h"
#include "esp_http_server.h"
#include "lwip/err.h"
#include "lwip/sys.h"
#include "driver/spi_master.h"

/* WiFi configuration */
#define EXAMPLE_ESP_WIFI_SSID      CONFIG_ESP_WIFI_SSID
#define EXAMPLE_ESP_WIFI_PASS      CONFIG_ESP_WIFI_PASSWORD
#define EXAMPLE_ESP_WIFI_CHANNEL   CONFIG_ESP_WIFI_CHANNEL
#define EXAMPLE_MAX_STA_CONN       CONFIG_ESP_MAX_STA_CONN

static const char *TAG = "wifi softAP";

/* Camera configuration */
#define CAMERA_PIN_PWDN -1
#define CAMERA_PIN_RESET -1
#define CAMERA_PIN_XCLK 15
#define CAMERA_PIN_SIOD 4
#define CAMERA_PIN_SIOC 5
#define CAMERA_PIN_D7 16
#define CAMERA_PIN_D6 17
#define CAMERA_PIN_D5 18
#define CAMERA_PIN_D4 12
#define CAMERA_PIN_D3 10
#define CAMERA_PIN_D2 8
#define CAMERA_PIN_D1 9
#define CAMERA_PIN_D0 11
#define CAMERA_PIN_VSYNC 6
#define CAMERA_PIN_HREF 7
#define CAMERA_PIN_PCLK 13

#define SPI_SCLK_OUT 21     /* SPI shared SCLK @ GPIO 21 */
#define SPI_SDO2     43     /* Serial Data Out 1 @ GPIO0 */
#define SPI_SDI2     44      /* Serial Data In 1 @ GPIO3 */
#define SPI_SDO3     45     /* Serial Data Out 2 @ GPIO45 */
#define SPI_SDI3     46     /* Serial Data In 2 @ GPIO46 */
#define SPI_CS       -1     /* Chip select is not being used, peripheral device's CS is pulled down to 0*/

// Function definitions
static void wifi_event_handler(void* arg, esp_event_base_t event_base, int32_t event_id, void* event_data);
void wifi_init_softap(void);
void init_camera();
esp_err_t stream_handler(httpd_req_t *req);
static void start_camera_server();
void init_spi_controllers();
esp_err_t ach1_handler(httpd_req_t *req);

// Global variables
spi_device_handle_t spi_device_2;
spi_device_handle_t spi_device_3;

static httpd_uri_t stream_uri = {
    .uri = "/stream",          // URI endpoint for video stream
    .method = HTTP_GET,         // HTTP GET method
    .handler = stream_handler,  // Handler function
    .user_ctx = NULL            // Optional user context
};

static httpd_uri_t ach1_uri = {
    .uri = "/ach1",             // URI endpoint for audio channel 1 stream
    .method = HTTP_GET,         // HTTP GET method
    .handler = ach1_handler,    // Handler function
    .user_ctx = NULL            // Optional user context
};

// In app_main, add after each major step:
void app_main(void) {
    ESP_LOGI(TAG, "Starting application...");
    
    esp_err_t ret = nvs_flash_init();
    while (ret == ESP_ERR_NVS_NO_FREE_PAGES || ret == ESP_ERR_NVS_NEW_VERSION_FOUND) {
      ESP_ERROR_CHECK(nvs_flash_erase());
      ret = nvs_flash_init();
    }
    ESP_ERROR_CHECK(ret);
    ESP_LOGI(TAG, "NVS initialized successfully");

    ESP_LOGI(TAG, "Initializing WiFi in AP mode");
    wifi_init_softap();
    
    ESP_LOGI(TAG, "Initializing camera");
    init_camera();
    
    ESP_LOGI(TAG, "Starting camera server");
    start_camera_server();

    ESP_LOGI(TAG, "Initializing SPI controllers");
    init_spi_controllers();
    
    ESP_LOGI(TAG, "Setup complete");
}

/* WiFi event handler */
static void wifi_event_handler(void* arg, esp_event_base_t event_base,
                               int32_t event_id, void* event_data) {
    if (event_id == WIFI_EVENT_AP_STACONNECTED) {
        wifi_event_ap_staconnected_t* event = (wifi_event_ap_staconnected_t*) event_data;
        ESP_LOGI(TAG, "station " MACSTR " join, AID=%d", MAC2STR(event->mac), event->aid);
    } else if (event_id == WIFI_EVENT_AP_STADISCONNECTED) {
        wifi_event_ap_stadisconnected_t* event = (wifi_event_ap_stadisconnected_t*) event_data;
        ESP_LOGI(TAG, "station " MACSTR " leave, AID=%d, reason=%d",
                 MAC2STR(event->mac), event->aid, event->reason);
    }
}

/* Initialize WiFi in SoftAP mode */
void wifi_init_softap(void) {
    ESP_ERROR_CHECK(esp_netif_init());
    ESP_ERROR_CHECK(esp_event_loop_create_default());
    esp_netif_create_default_wifi_ap();

    wifi_init_config_t cfg = WIFI_INIT_CONFIG_DEFAULT();
    ESP_ERROR_CHECK(esp_wifi_init(&cfg));

    ESP_ERROR_CHECK(esp_event_handler_instance_register(WIFI_EVENT,
                                                        ESP_EVENT_ANY_ID,
                                                        &wifi_event_handler,
                                                        NULL,
                                                        NULL));

    wifi_config_t wifi_config = {
        .ap = {
            .ssid = EXAMPLE_ESP_WIFI_SSID,
            .ssid_len = strlen(EXAMPLE_ESP_WIFI_SSID),
            .channel = EXAMPLE_ESP_WIFI_CHANNEL,
            .password = EXAMPLE_ESP_WIFI_PASS,
            .max_connection = EXAMPLE_MAX_STA_CONN,
            .authmode = WIFI_AUTH_WPA2_PSK,
            .pmf_cfg = {
                    .required = true,
            },
        },
    };
    if (strlen(EXAMPLE_ESP_WIFI_PASS) == 0) {
        wifi_config.ap.authmode = WIFI_AUTH_OPEN;
    }

    ESP_ERROR_CHECK(esp_wifi_set_mode(WIFI_MODE_AP));
    ESP_ERROR_CHECK(esp_wifi_set_config(WIFI_IF_AP, &wifi_config));
    ESP_ERROR_CHECK(esp_wifi_start());

    ESP_LOGI(TAG, "wifi_init_softap finished. SSID:%s password:%s channel:%d",
             EXAMPLE_ESP_WIFI_SSID, EXAMPLE_ESP_WIFI_PASS, EXAMPLE_ESP_WIFI_CHANNEL);
}

/* Initialize the Camera */
void init_camera() {
    camera_config_t config;
    config.ledc_channel = LEDC_CHANNEL_0;
    config.ledc_timer = LEDC_TIMER_0;
    config.pin_d0 = CAMERA_PIN_D0;
    config.pin_d1 = CAMERA_PIN_D1;
    config.pin_d2 = CAMERA_PIN_D2;
    config.pin_d3 = CAMERA_PIN_D3;
    config.pin_d4 = CAMERA_PIN_D4;
    config.pin_d5 = CAMERA_PIN_D5;
    config.pin_d6 = CAMERA_PIN_D6;
    config.pin_d7 = CAMERA_PIN_D7;
    config.pin_xclk = CAMERA_PIN_XCLK;
    config.pin_pclk = CAMERA_PIN_PCLK;
    config.pin_vsync = CAMERA_PIN_VSYNC;
    config.pin_href = CAMERA_PIN_HREF;
    config.pin_sccb_sda = CAMERA_PIN_SIOD;
    config.pin_sccb_scl = CAMERA_PIN_SIOC;
    config.pin_pwdn = CAMERA_PIN_PWDN;
    config.pin_reset = CAMERA_PIN_RESET;
    config.xclk_freq_hz = 20000000;
    config.pixel_format = PIXFORMAT_JPEG;
    config.frame_size = FRAMESIZE_VGA;
    config.jpeg_quality = 12;
    config.fb_count = 2;

    // Camera init
    esp_err_t err = esp_camera_init(&config);
    if (err != ESP_OK) {
        ESP_LOGE(TAG, "Camera Init Failed");
    }
}
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

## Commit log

2024-11-13 Face, Video scrape, Audio scrape, subtitles
    This is the current Facedetection3.0 code which implements the video scraping into the OpenCV display. the audio scraping is used in unison with this to display the subtitles as well. And the whisper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
2024-11-14 updated file structure
    [CameraSubBoard.kicad_sch, ESP32R.kicad_sch, ESP32S2comV2.2-BOM.csv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]
2025-01-24 added version 3 for the board
    [CameraSubBoard.kicad_sch, ESP32R.kicad_sch, ESP32S3comV3.kicad_pcb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]
2025-01-29 Version 3.1
    [CameraSubBoard.kicad_sch, ESP32R.kicad_sch, ESP32S3comV3.1.kicad_pcb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]
2025-02-03 add PCB Versions
    [CameraSubBoard.kicad_sch, ESP32R.kicad_sch, ESP32S3comV3.2.kicad_pcb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]
2025-02-19 production files added
    [bom.csv, designators.csv, positions.csv]
2025-04-13 arm board firmware
    [configure to flash.txt]
2025-04-13 added pin layout
2025-04-14 Squashed commit of the following:
    commit cd66e0a1305f8fe2782743b6b9fd62e6e4d255bb
    Author: Koalaven <102919896+Koalaven@users.noreply.github.com>
    Date: Mon Apr 14 14:12:40 2025 -0400
    moved to be closer file format
    commit 58886cd4b8a11e447f16aa333d6f8a5f13fe3d6a
    Author: leeyumsk <123519050+leeyumsk@users.noreply.github.com>
    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
2025-04-14 added cad models
    frames
2025-04-14 assembly picture
2025-04-14 Rename Screenshot 2025-04-14 152832.png to assemblypic.png
2025-04-14 Update README.md
    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
